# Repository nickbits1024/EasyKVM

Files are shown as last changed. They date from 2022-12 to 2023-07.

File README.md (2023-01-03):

# _Easy KVM_

## About Easy KVM

Easy KVM is a Wi-Fi enabled hybrid KVM.  It acts a an USB sharing switch and VESA DDC/CI switcher.  It does not touch the video signal which eliminates a lot of issues found with standard KVMs.

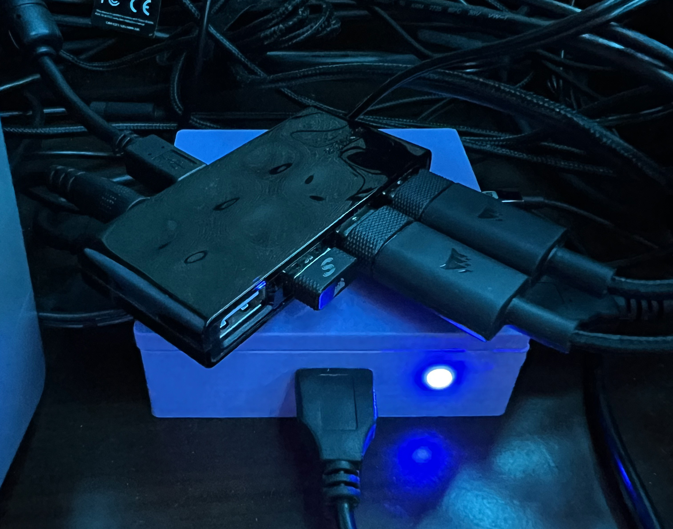
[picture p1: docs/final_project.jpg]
Final Project

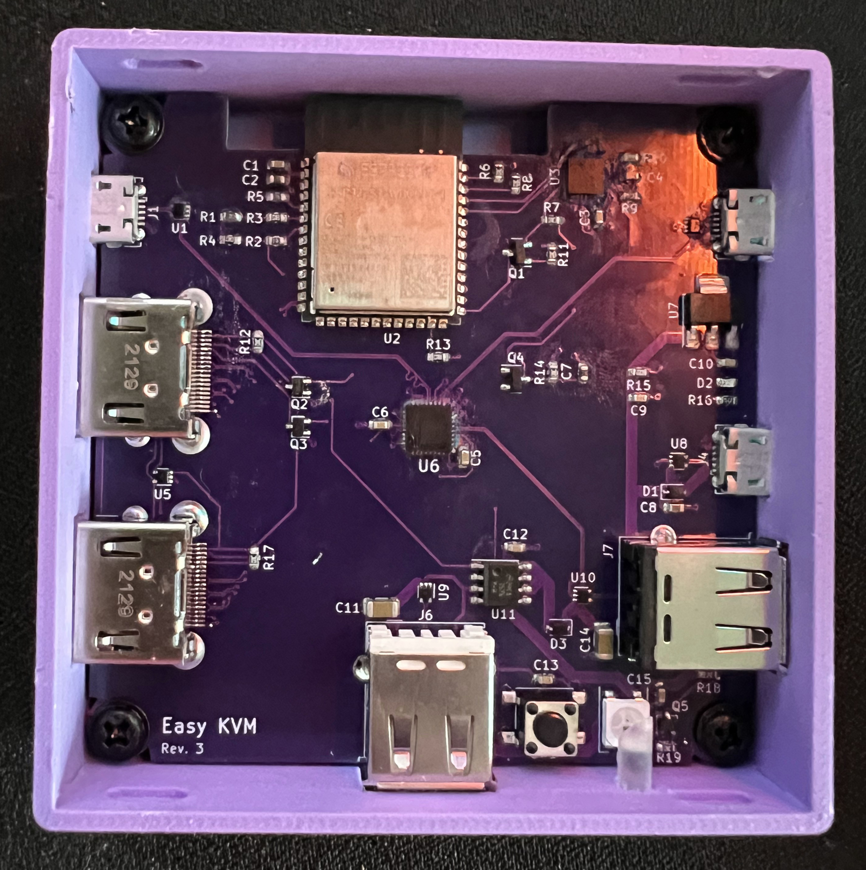
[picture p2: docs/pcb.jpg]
PCB

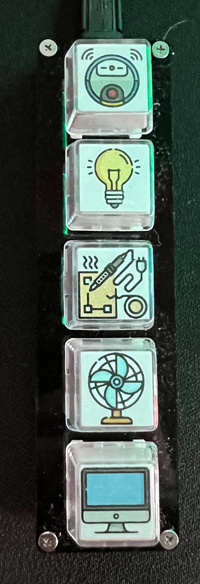
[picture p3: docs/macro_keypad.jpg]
Macro keypad


## Features

* Single USB 2.0 high speed capable port to be used with an external USB hub
* Wi-Fi control
* HDMI passthrough
* USB keyboard for macros and port switching
* Control monitor power state
* Integrated with Home Assistant

## External Requirements
* USB macro keypad e.g. [Amazon](https://www.amazon.com/gp/product/B09CKT8B7Y) [AliExpress](https://www.aliexpress.us/item/3256804248423460.html)
* USB 2.0 high speed hub e.g. [Amazon](https://www.amazon.com/gp/product/B005A0B3FG)
* Monitor with an HDMI port that supports VESA DDC/CI

## Port Setup
1. Connect source HDMI cable from video card to either one of the HDMI ports
2. Connect other HDMI port to monitor
3. Connect J1 Micro USB (top left) to PC1 USB
4. Connect J2 Micro USB (top right) to PC2 USB
5. Connect J6 Micro USB (bottom renter) to macro keypad
6. Connect J7 USB (bottom right) to USB hub
7. Connect J4 Micro USB (Center right) to either USB power or PC (for programming and serial monitoring)

## Wi-Fi Setup
Wi-Fi network selection is done through bluetooth.  
1. Download nRF Connect and connect to KVM
2. Open the client services tab and click Write Value the (up arrow) on the characteristic ending with an UUID of 29.  
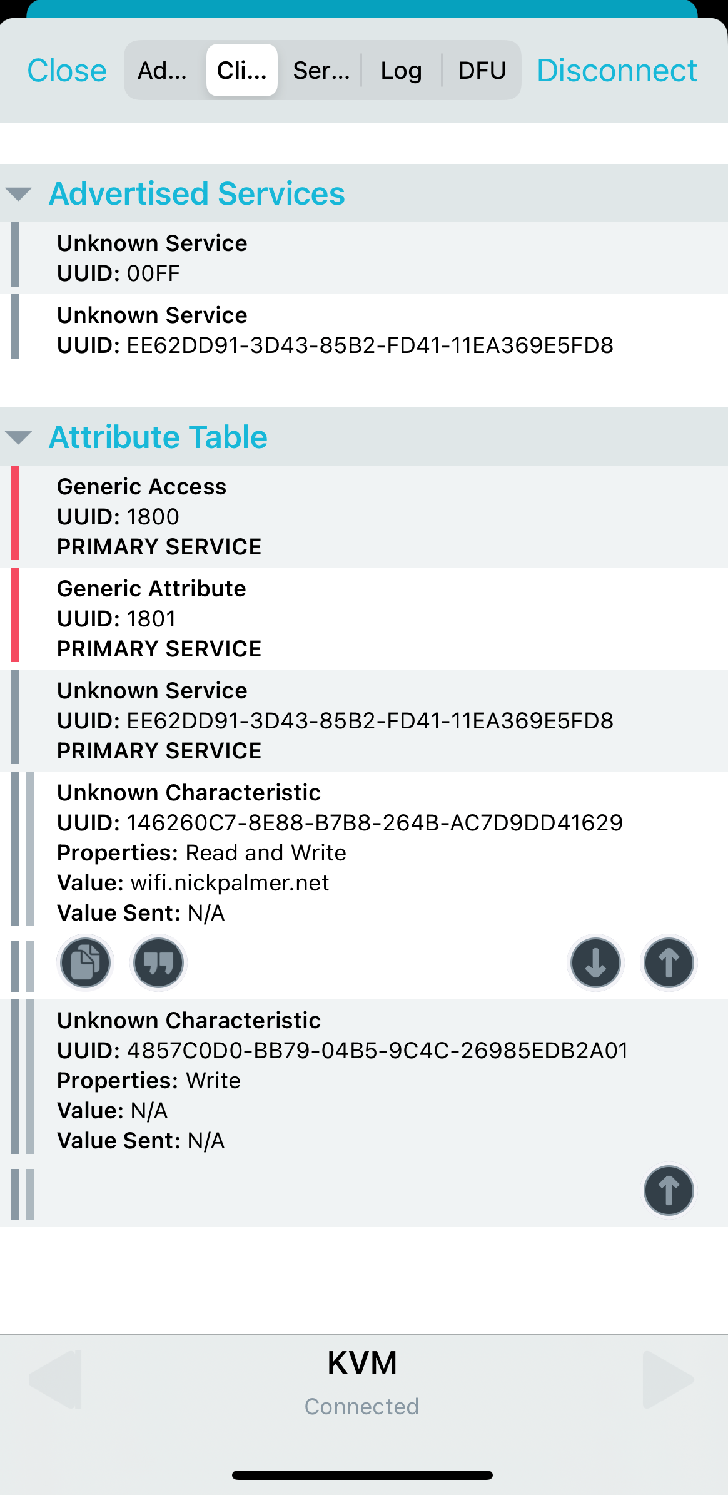
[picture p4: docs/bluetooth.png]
Characteristics

3. Click the UTF-8 tab and enter the network SSID and click Write.
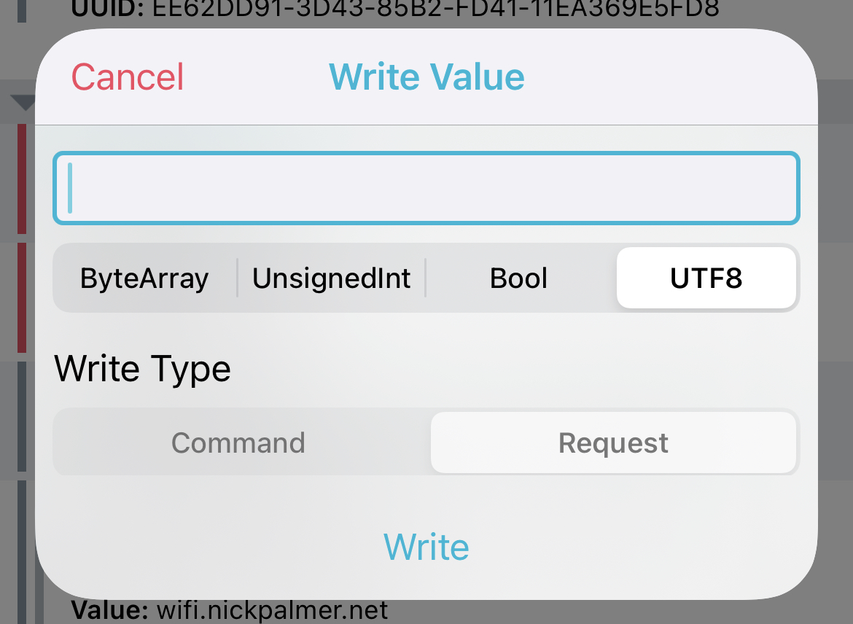
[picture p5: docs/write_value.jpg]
Write Value Screenshot

4. Click Write Value on the characteristic ending in 01.  This is the Wi-Fi password.  After clicking Write, the KVM should connect to the network.

## WebServer End Points

| URL | Method | Function | Payload |
| --- | --- | --- | --- |
|/config|GET|Open configuration page||
|/monitor|GET|Return monitor state|`{	"on":	true }`|
|/monitor|POST|Set monitor state|`{	"on":	true }`|
|/kvm|GET|Return selected KVM port|`{ "kvm":	1 }`|
|/kvm/1|GET|Select KVM port 1||
|/kvm/2|GET|Select KVM port 2||

## Home Assistant
The KVM needs a Long-Lived Access Token to interact with home assistant.  Create one from the home assistant profile page and save it for later (e.g. notepad)

### Monitor Switch

Copy code below into the home assistant switches.yaml file.  This will create a switch in home assistant that can be used to turn the connected monitor on and off.
```
- platform: rest
  name: "Office Monitor"
  unique_id: 08a5830e-3309-4998-9d17-7ea7ecf154fd
  resource: http://<<KVM_HOST_NAME_OR_IP>>/monitor
  timeout: 30
  body_on: '{"on": true}'
  body_off: '{"on": false}'
  is_on_template: "{{ value_json.on }}"
  headers:
    Content-Type: application/json
```

## Configuration
1. Determine the IP of the KVM either from router UI or connecting the KVM to a computer and viewing the serial output.
2. Navigate to http://KVM_IP/config
3. Select the desired source and RGB led color for each input
4. Enter home assistant URL and previously created access token
5. Configure the macro keypad functions
6. Click save

Note clipboard import/export only work if you have the KVM behind an https proxy

## Usage
Once properly configured, the inputs can be switched using the configured macro keypad button or through the web server end points

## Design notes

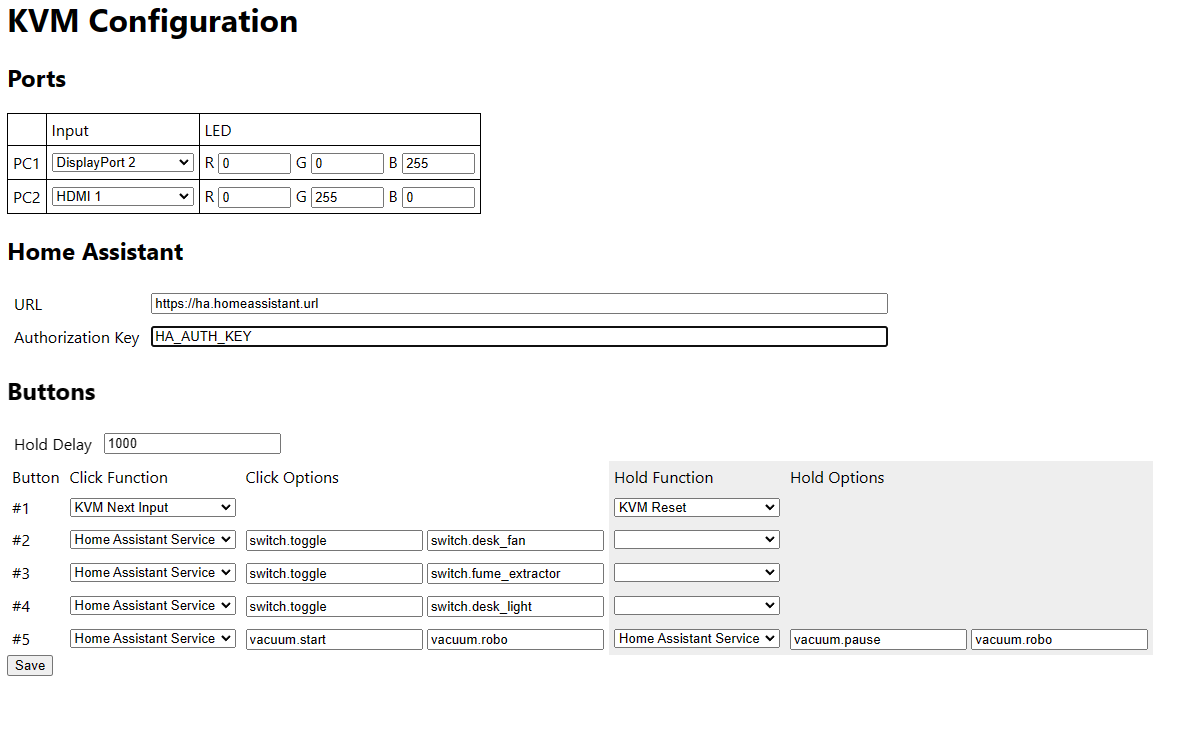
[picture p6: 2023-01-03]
docs/config.png

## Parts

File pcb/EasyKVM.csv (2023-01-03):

Source: | C:\Users\Nick\repos\EasyKVM\pcb\EasyKVM.kicad_sch
Date: | 12/30/2022 3:57:13 PM
Tool: | Eeschema (6.0.8)
Generator: | C:\Program Files\KiCad\6.0\bin\scripting\plugins/bom_csv_grouped_by_value.py
Component Count: | 62
Individual Components:
Item | Qty | Reference(s) | Value | LibPart | Footprint | Datasheet | Description | Height | Manufacturer_Name | Manufacturer_Part_Number | Mouser Part Number | Mouser Price/Stock
 |  | C1 | 0.1uF | Device:C | Capacitor_SMD:C_0603_1608Metric | ~
 |  | C2 | 10uF | Device:C | Capacitor_SMD:C_0603_1608Metric | ~
 |  | C3 | 4.7uF | Device:C | Capacitor_SMD:C_0603_1608Metric | ~
 |  | C4 | 0.1uF | Device:C | Capacitor_SMD:C_0603_1608Metric | ~
 |  | C5 | 0.1uF | Device:C | Capacitor_SMD:C_0603_1608Metric | ~
 |  | C6 | 0.1uF | Device:C | Capacitor_SMD:C_0603_1608Metric | ~
 |  | C7 | 1uF | Device:C | Capacitor_SMD:C_0603_1608Metric | ~
 |  | C8 | 10uF | Device:C | Capacitor_SMD:C_0603_1608Metric | ~
 |  | C9 | 4.7uF | Device:C | Capacitor_SMD:C_0603_1608Metric | ~
 |  | C10 | 4.7uF | Device:C | Capacitor_SMD:C_0603_1608Metric | ~
 |  | C11 | 100uF | Device:C | Capacitor_SMD:C_1206_3216Metric | ~
 |  | C12 | 0.1uF | Device:C | Capacitor_SMD:C_0603_1608Metric | ~
 |  | C13 | 0.1uF | Device:C | Capacitor_SMD:C_0603_1608Metric | ~
 |  | C14 | 100uF | Device:C | Capacitor_SMD:C_1206_3216Metric | ~
 |  | C15 | 0.1uF | Device:C | Capacitor_SMD:C_0603_1608Metric | ~
 |  | D1 | 1N5819 | Diode:1N5819 | Diode_SMD:D_SOD-323 | http://www.vishay.com/docs/88525/1n5817.pdf
 |  | D2 | RED LED | Device:LED | Capacitor_SMD:C_0603_1608Metric | ~
 |  | D3 | 1N5819 | Diode:1N5819 | Diode_SMD:D_SOD-323 | http://www.vishay.com/docs/88525/1n5817.pdf
 |  | D4 | SK6812 | LED:SK6812 | LED_SMD:LED_SK6812_PLCC4_5.0x5.0mm_P3.2mm | https://cdn-shop.adafruit.com/product-files/1138/SK6812+LED+datasheet+.pdf
 |  | J1 | USB_B_Micro | Connector:USB_B_Micro | Connector_USB:USB_Micro-B_Molex-105017-0001 | ~
 |  | J2 | USB_B_Micro | Connector:USB_B_Micro | Connector_USB:USB_Micro-B_Molex-105017-0001 | ~
 |  | J3 | HDMI_A | Connector:HDMI_A | MyParts:2086581051 | https://en.wikipedia.org/wiki/HDMI
 |  | J4 | USB_B_Micro | Connector:USB_B_Micro | Connector_USB:USB_Micro-B_Molex-105017-0001 | ~
 |  | J5 | HDMI_A | Connector:HDMI_A | MyParts:2086581051 | https://en.wikipedia.org/wiki/HDMI
 |  | J6 | USB_A | Connector:USB_A | Connector_USB:USB_A_Molex_67643_Horizontal | ~
 |  | J7 | USB_A | Connector:USB_A | Connector_USB:USB_A_Molex_67643_Horizontal | ~
 |  | Q1 | MMBT3904 | Transistor_BJT:MMBT3904 | Package_TO_SOT_SMD:SOT-23 | https://www.onsemi.com/pub/Collateral/2N3903-D.PDF
 |  | Q2 | BSS138 | Transistor_FET:BSS138 | Package_TO_SOT_SMD:SOT-323_SC-70 | https://www.onsemi.com/pub/Collateral/BSS138-D.PDF
 |  | Q3 | BSS138 | Transistor_FET:BSS138 | Package_TO_SOT_SMD:SOT-323_SC-70 | https://www.onsemi.com/pub/Collateral/BSS138-D.PDF
 |  | Q4 | MMBT3904 | Transistor_BJT:MMBT3904 | Package_TO_SOT_SMD:SOT-23 | https://www.onsemi.com/pub/Collateral/2N3903-D.PDF
 |  | Q5 | BSS138 | Transistor_FET:BSS138 | Package_TO_SOT_SMD:SOT-323_SC-70 | https://www.onsemi.com/pub/Collateral/BSS138-D.PDF
 |  | R1 | 100K | Device:R | Resistor_SMD:R_0603_1608Metric | ~
 |  | R2 | 1K | Device:R | Resistor_SMD:R_0603_1608Metric | ~
 |  | R3 | 1K | Device:R | Resistor_SMD:R_0603_1608Metric | ~
 |  | R4 | 100K | Device:R | Resistor_SMD:R_0603_1608Metric | ~
 |  | R5 | 1K | Device:R | Resistor_SMD:R_0603_1608Metric | ~
 |  | R6 | 10K | Device:R | Resistor_SMD:R_0603_1608Metric | ~
 |  | R7 | 10K | Device:R | Resistor_SMD:R_0603_1608Metric | ~
 |  | R8 | 10K | Device:R | Resistor_SMD:R_0603_1608Metric | ~
 |  | R9 | 47K | Device:R | Resistor_SMD:R_0603_1608Metric | ~
 |  | R10 | 1K | Device:R | Resistor_SMD:R_0603_1608Metric | ~
 |  | R11 | 10K | Device:R | Resistor_SMD:R_0603_1608Metric | ~
 |  | R12 | 10K | Device:R | Resistor_SMD:R_0603_1608Metric | ~
 |  | R13 | 1K | Device:R | Resistor_SMD:R_0603_1608Metric | ~
 |  | R14 | 10K | Device:R | Resistor_SMD:R_0603_1608Metric | ~
 |  | R15 | 22K | Device:R | Resistor_SMD:R_0603_1608Metric | ~
 |  | R16 | 5.1K | Device:R | Resistor_SMD:R_0603_1608Metric | ~
 |  | R17 | 10K | Device:R | Resistor_SMD:R_0603_1608Metric | ~
 |  | R18 | 10K | Device:R | Resistor_SMD:R_0603_1608Metric | ~
 |  | R19 | 10K | Device:R | Resistor_SMD:R_0603_1608Metric | ~
 |  | SW1 | RESET | Switch:SW_Push | Button_Switch_SMD:SW_Push_1P1T_NO_6x6mm_H9.5mm | ~
 |  | U1 | SP3003-02XTG | :SP3003-02XTG_3 | Package_TO_SOT_SMD:Diodes_SOT-553
 |  | U2 | ESP32-S3-WROOM-1 | Espressif:ESP32-S3-WROOM-1 | Espressif:ESP32-S3-WROOM-1 | https://www.espressif.com/sites/default/files/documentation/esp32-s3-wroom-1_wroom-1u_datasheet_en.pdf
 |  | U3 | CP2102N-Axx-xQFN24 | Interface_USB:CP2102N-Axx-xQFN24 | Package_DFN_QFN:QFN-24-1EP_4x4mm_P0.5mm_EP2.6x2.6mm | https://www.silabs.com/documents/public/data-sheets/cp2102n-datasheet.pdf
 |  | U4 | SP3003-02XTG | :SP3003-02XTG_4 | Package_TO_SOT_SMD:Diodes_SOT-553
 |  | U5 | SP3003-02XTG | MyParts:SP3003-02XTG | Package_TO_SOT_SMD:Diodes_SOT-553
 |  | U6 | MAX4999ETJ+ | MAX4999ETJ+:MAX4999ETJ+ | MyParts:QFN50P500X500X80-33N | https://datasheets.maximintegrated.com/en/ds/MAX4999.pdf | Maxim MAX4999ETJ+, Multiplexer Single 8:1 Multiplexer, 3 3.6 V, 32-Pin TQFN | 0.8 | Maxim Integrated | MAX4999ETJ+ | 700-MAX4999ETJ | https://www.mouser.co.uk/ProductDetail/Maxim-Integrated/MAX4999ETJ%2b?qs=LHmEVA8xxfbu5fCaz0LQrg%3D%3D
 |  | U7 | AP7361C-33E | Regulator_Linear:AP7361C-33E | Package_TO_SOT_SMD:SOT-223-3_TabPin2 | https://www.diodes.com/assets/Datasheets/AP7361C.pdf
 |  | U8 | SP3003-02XTG | :SP3003-02XTG_2 | Package_TO_SOT_SMD:Diodes_SOT-553
 |  | U9 | SP3003-02XTG | :SP3003-02XTG_5 | Package_TO_SOT_SMD:Diodes_SOT-553
 |  | U10 | SP3003-02XTG | :SP3003-02XTG_1 | Package_TO_SOT_SMD:Diodes_SOT-553
 |  | U11 | LM3525M-H | MyParts:LM3525M-H | Package_SO:SOIC-8_3.9x4.9mm_P1.27mm
Collated Components:
Item | Qty | Reference(s) | Value | LibPart | Footprint | Datasheet | Description | Height | Manufacturer_Name | Manufacturer_Part_Number | Mouser Part Number | Mouser Price/Stock
1 | 7 | C1, C4, C5, C6, C12, C13, C15 | 0.1uF | Device:C | Capacitor_SMD:C_0603_1608Metric | ~
2 | 2 | C2, C8 | 10uF | Device:C | Capacitor_SMD:C_0603_1608Metric | ~
3 | 3 | C3, C9, C10 | 4.7uF | Device:C | Capacitor_SMD:C_0603_1608Metric | ~
4 | 1 | C7 | 1uF | Device:C | Capacitor_SMD:C_0603_1608Metric | ~
5 | 2 | C11, C14 | 100uF | Device:C | Capacitor_SMD:C_1206_3216Metric | ~
6 | 2 | D1, D3 | 1N5819 | Diode:1N5819 | Diode_SMD:D_SOD-323 | http://www.vishay.com/docs/88525/1n5817.pdf
7 | 1 | D2 | RED LED | Device:LED | Capacitor_SMD:C_0603_1608Metric | ~
8 | 1 | D4 | SK6812 | LED:SK6812 | LED_SMD:LED_SK6812_PLCC4_5.0x5.0mm_P3.2mm | https://cdn-shop.adafruit.com/product-files/1138/SK6812+LED+datasheet+.pdf
9 | 3 | J1, J2, J4 | USB_B_Micro | Connector:USB_B_Micro | Connector_USB:USB_Micro-B_Molex-105017-0001 | ~
10 | 2 | J3, J5 | HDMI_A | Connector:HDMI_A | MyParts:2086581051 | https://en.wikipedia.org/wiki/HDMI
11 | 2 | J6, J7 | USB_A | Connector:USB_A | Connector_USB:USB_A_Molex_67643_Horizontal | ~
12 | 2 | Q1, Q4 | MMBT3904 | Transistor_BJT:MMBT3904 | Package_TO_SOT_SMD:SOT-23 | https://www.onsemi.com/pub/Collateral/2N3903-D.PDF
13 | 3 | Q2, Q3, Q5 | BSS138 | Transistor_FET:BSS138 | Package_TO_SOT_SMD:SOT-323_SC-70 | https://www.onsemi.com/pub/Collateral/BSS138-D.PDF
14 | 2 | R1, R4 | 100K | Device:R | Resistor_SMD:R_0603_1608Metric | ~
15 | 5 | R2, R3, R5, R10, R13 | 1K | Device:R | Resistor_SMD:R_0603_1608Metric | ~
16 | 9 | R6, R7, R8, R11, R12, R14, R17, R18, R19 | 10K | Device:R | Resistor_SMD:R_0603_1608Metric | ~
17 | 1 | R9 | 47K | Device:R | Resistor_SMD:R_0603_1608Metric | ~
18 | 1 | R15 | 22K | Device:R | Resistor_SMD:R_0603_1608Metric | ~
19 | 1 | R16 | 5.1K | Device:R | Resistor_SMD:R_0603_1608Metric | ~
20 | 1 | SW1 | RESET | Switch:SW_Push | Button_Switch_SMD:SW_Push_1P1T_NO_6x6mm_H9.5mm | ~
21 | 1 | U1 | SP3003-02XTG | :SP3003-02XTG_3 | Package_TO_SOT_SMD:Diodes_SOT-553
22 | 1 | U2 | ESP32-S3-WROOM-1 | Espressif:ESP32-S3-WROOM-1 | Espressif:ESP32-S3-WROOM-1 | https://www.espressif.com/sites/default/files/documentation/esp32-s3-wroom-1_wroom-1u_datasheet_en.pdf
23 | 1 | U3 | CP2102N-Axx-xQFN24 | Interface_USB:CP2102N-Axx-xQFN24 | Package_DFN_QFN:QFN-24-1EP_4x4mm_P0.5mm_EP2.6x2.6mm | https://www.silabs.com/documents/public/data-sheets/cp2102n-datasheet.pdf
24 | 1 | U4 | SP3003-02XTG | :SP3003-02XTG_4 | Package_TO_SOT_SMD:Diodes_SOT-553
25 | 1 | U5 | SP3003-02XTG | MyParts:SP3003-02XTG | Package_TO_SOT_SMD:Diodes_SOT-553
26 | 1 | U6 | MAX4999ETJ+ | MAX4999ETJ+:MAX4999ETJ+ | MyParts:QFN50P500X500X80-33N | https://datasheets.maximintegrated.com/en/ds/MAX4999.pdf | Maxim MAX4999ETJ+, Multiplexer Single 8:1 Multiplexer, 3 3.6 V, 32-Pin TQFN | 0.8 | Maxim Integrated | MAX4999ETJ+ | 700-MAX4999ETJ | https://www.mouser.co.uk/ProductDetail/Maxim-Integrated/MAX4999ETJ%2b?qs=LHmEVA8xxfbu5fCaz0LQrg%3D%3D
27 | 1 | U7 | AP7361C-33E | Regulator_Linear:AP7361C-33E | Package_TO_SOT_SMD:SOT-223-3_TabPin2 | https://www.diodes.com/assets/Datasheets/AP7361C.pdf
28 | 1 | U8 | SP3003-02XTG | :SP3003-02XTG_2 | Package_TO_SOT_SMD:Diodes_SOT-553
29 | 1 | U9 | SP3003-02XTG | :SP3003-02XTG_5 | Package_TO_SOT_SMD:Diodes_SOT-553
30 | 1 | U10 | SP3003-02XTG | :SP3003-02XTG_1 | Package_TO_SOT_SMD:Diodes_SOT-553
31 | 1 | U11 | LM3525M-H | MyParts:LM3525M-H | Package_SO:SOIC-8_3.9x4.9mm_P1.27mm

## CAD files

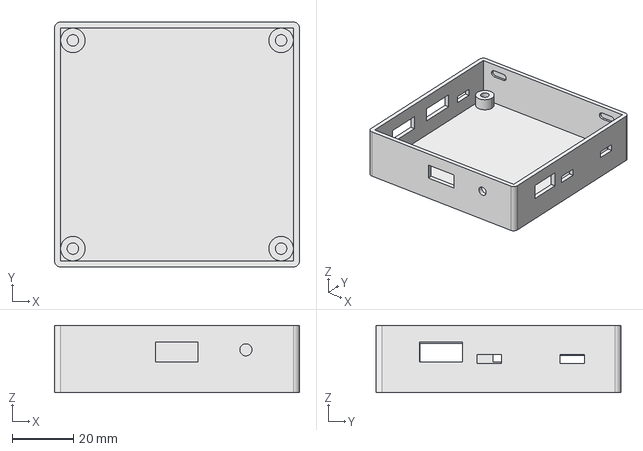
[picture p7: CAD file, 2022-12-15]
cad/Bottom.step
80.0 x 80.0 x 22.0 mm

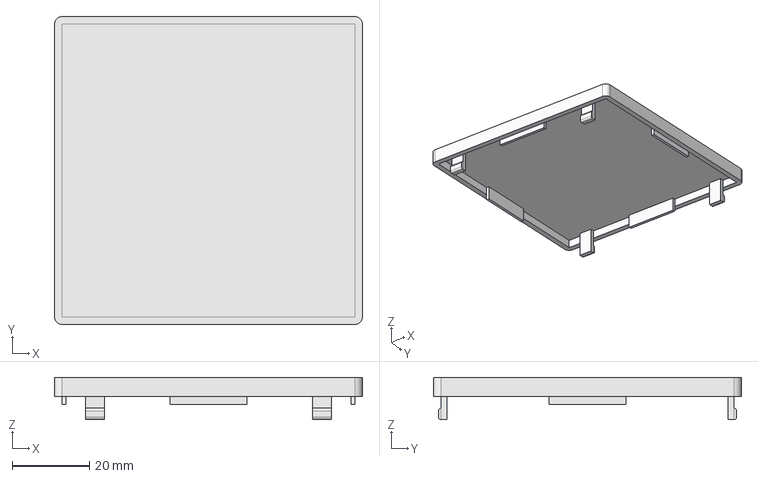
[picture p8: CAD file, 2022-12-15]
cad/Top.step
80.0 x 80.0 x 11.0 mm

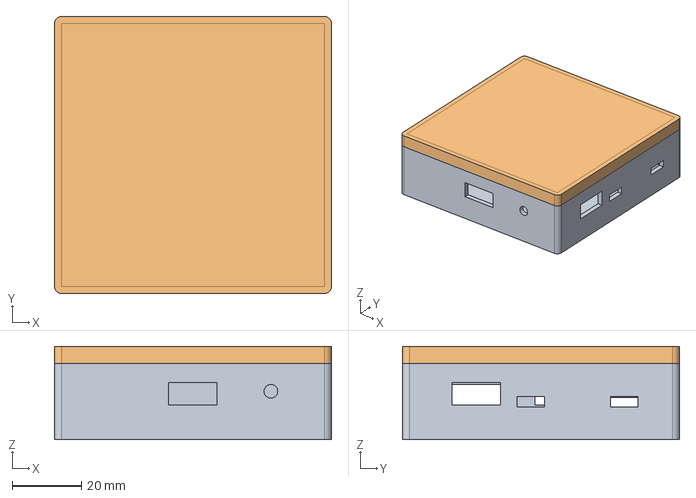
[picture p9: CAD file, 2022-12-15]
cad/EasyKVM-case.FCStd
80.0 x 80.0 x 27.0 mm
Bottom
Top

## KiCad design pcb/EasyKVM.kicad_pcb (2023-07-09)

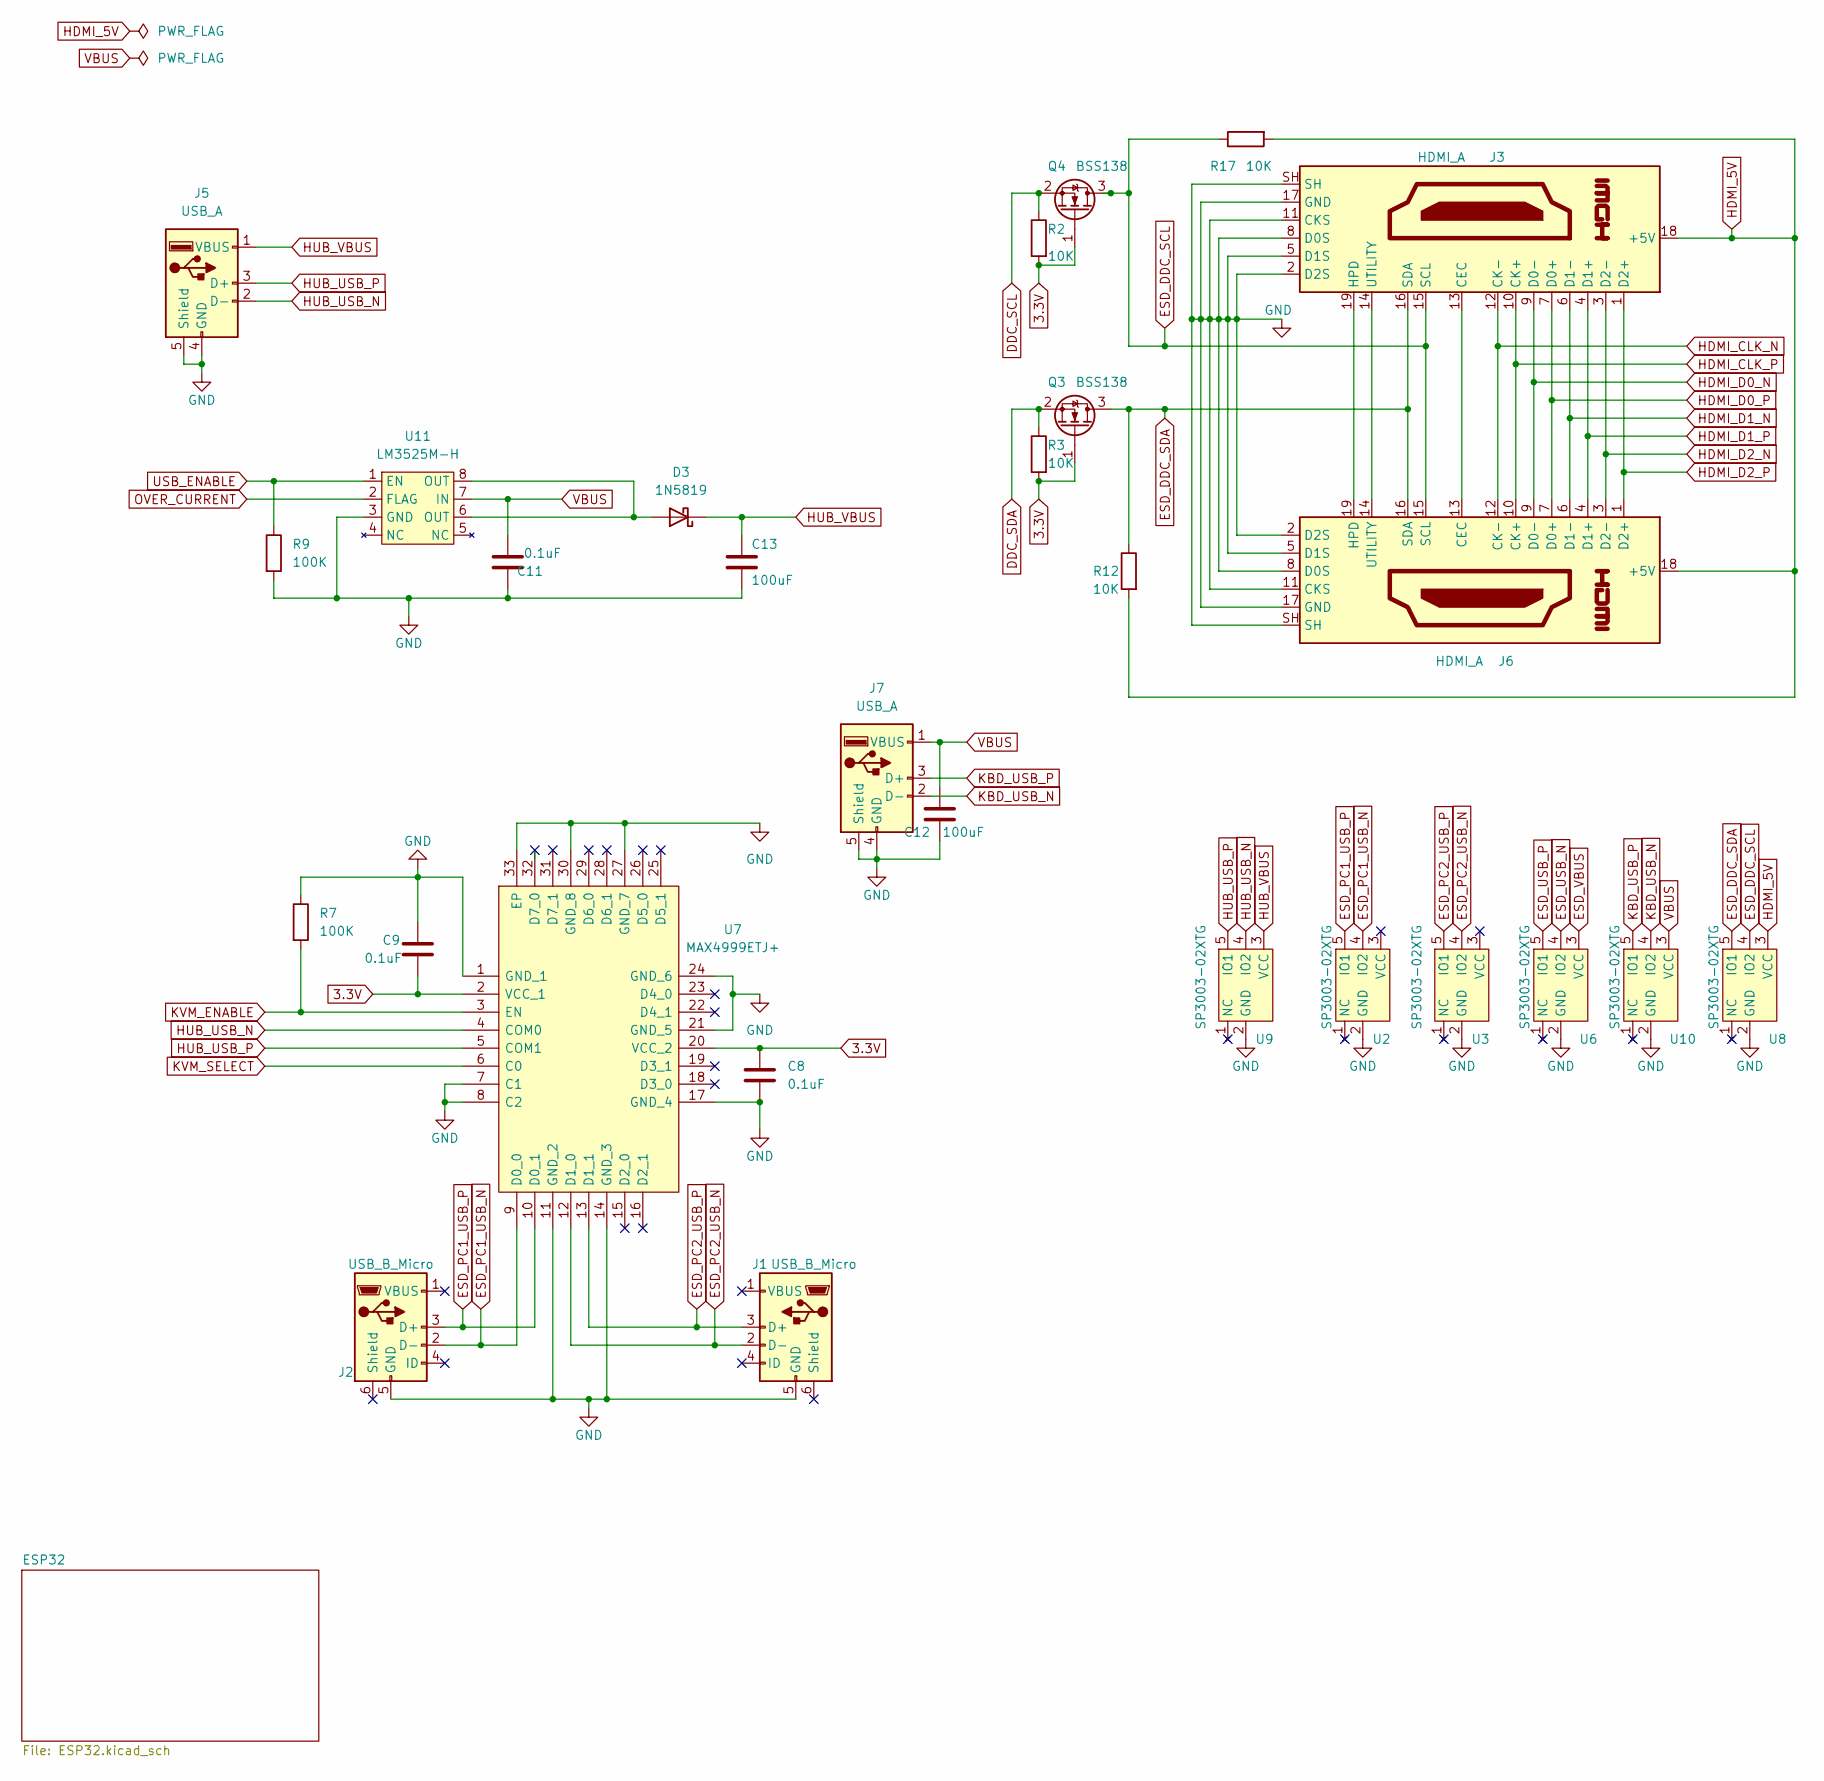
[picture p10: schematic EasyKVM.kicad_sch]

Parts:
C8, C9, C11: 0.1uF; C_0603_1608Metric
C12, C13: 100uF; C_1206_3216Metric
D3: 1N5819; D_SOD-323
J1, J2: USB_B_Micro; USB_Micro-B_Molex-105017-0001
J3, J6: HDMI_A; 2086581051
J5, J7: USB_A; USB_A_Molex_67643_Horizontal
Q3, Q4: BSS138; SOT-323_SC-70
R2, R3, R12, R17: 10K; R_0603_1608Metric
R7, R9: 100K; R_0603_1608Metric
U2, U3, U6, U8, U9, U10: SP3003-02XTG; Diodes_SOT-553
U7: MAX4999ETJ+; QFN50P500X500X80-33N; Manufacturer_Part_Number MAX4999ETJ+; Mouser Part Number 700-MAX4999ETJ
U11: LM3525M-H; SOIC-8_3.9x4.9mm_P1.27mm

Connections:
3.3V: C8.2, C9.1, Q3.1 (G), Q4.1 (G), R2.2, R3.2, U7.2 (VCC_1), U7.20 (VCC_2); also elsewhere on the board
DDC_SCL: Q4.2 (S), R2.1; also elsewhere on the board
DDC_SDA: Q3.2 (S), R3.1; also elsewhere on the board
ESD_DDC_SCL: J3.15 (SCL), J6.15 (SCL), Q4.3 (D), R17.1, U8.4 (IO2)
ESD_DDC_SDA: J3.16 (SDA), J6.16 (SDA), Q3.3 (D), R12.1, U8.5 (IO1)
ESD_PC1_USB_N: J2.2 (D-), U2.4 (IO2), U7.9 (D0_0)
ESD_PC1_USB_P: J2.3 (D+), U2.5 (IO1), U7.10 (D0_1)
ESD_PC2_USB_N: J1.2 (D-), U3.4 (IO2), U7.12 (D1_0)
ESD_PC2_USB_P: J1.3 (D+), U3.5 (IO1), U7.13 (D1_1)
ESD_USB_N: U6.4 (IO2); also elsewhere on the board
ESD_USB_P: U6.5 (IO1); also elsewhere on the board
ESD_VBUS: U6.3 (VCC); also elsewhere on the board
GND: C8.1, C9.2, C11.2, C12.2, C13.1, J1.5 (GND), J2.5 (GND), J3.2 (D2S), J3.5 (D1S), J3.8 (D0S), J3.11 (CKS), J3.17 (GND), J3.SH, J5.4 (GND), J5.5 (Shield), J6.2 (D2S), J6.5 (D1S), J6.8 (D0S), J6.11 (CKS), J6.17 (GND), J6.SH, J7.4 (GND), J7.5 (Shield), R7.1, R9.2, U2.2 (GND), U3.2 (GND), U6.2 (GND), U7.1 (GND_1), U7.7 (C1), U7.8 (C2), U7.11 (GND_2), U7.14 (GND_3), U7.17 (GND_4), U7.21 (GND_5), U7.24 (GND_6), U7.27 (GND_7), U7.30 (GND_8), U7.33 (EP), U8.2 (GND), U9.2 (GND), U10.2 (GND), U11.3 (GND); also elsewhere on the board
HDMI_5V: J3.18 (+5V), J6.18 (+5V), R12.2, R17.2, U8.3 (VCC)
HDMI_CLK_N: J3.12 (CK-), J6.12 (CK-)
HDMI_CLK_P: J3.10 (CK+), J6.10 (CK+)
HDMI_D0_N: J3.9 (D0-), J6.9 (D0-)
HDMI_D0_P: J3.7 (D0+), J6.7 (D0+)
HDMI_D1_N: J3.6 (D1-), J6.6 (D1-)
HDMI_D1_P: J3.4 (D1+), J6.4 (D1+)
HDMI_D2_N: J3.3 (D2-), J6.3 (D2-)
HDMI_D2_P: J3.1 (D2+), J6.1 (D2+)
HUB_USB_N: J5.2 (D-), U7.4 (COM0), U9.4 (IO2)
HUB_USB_P: J5.3 (D+), U7.5 (COM1), U9.5 (IO1)
HUB_VBUS: C13.2, D3.1 (K), J5.1 (VBUS), U9.3 (VCC)
KBD_USB_N: J7.2 (D-), U10.4 (IO2); also elsewhere on the board
KBD_USB_P: J7.3 (D+), U10.5 (IO1); also elsewhere on the board
KVM_ENABLE: R7.2, U7.3 (EN); also elsewhere on the board
KVM_SELECT: U7.6 (C0); also elsewhere on the board
unnamed: D3.2 (A), U11.6 (OUT), U11.8 (OUT)
unnamed: J3.13 (CEC), J6.13 (CEC)
unnamed: J3.14 (UTILITY), J6.14 (UTILITY)
unnamed: J3.19 (HPD), J6.19 (HPD)
OVER_CURRENT: U11.2 (FLAG); also elsewhere on the board
USB_ENABLE: R9.1, U11.1 (EN); also elsewhere on the board
VBUS: C11.1, C12.1, J7.1 (VBUS), U10.3 (VCC), U11.7 (IN); also elsewhere on the board

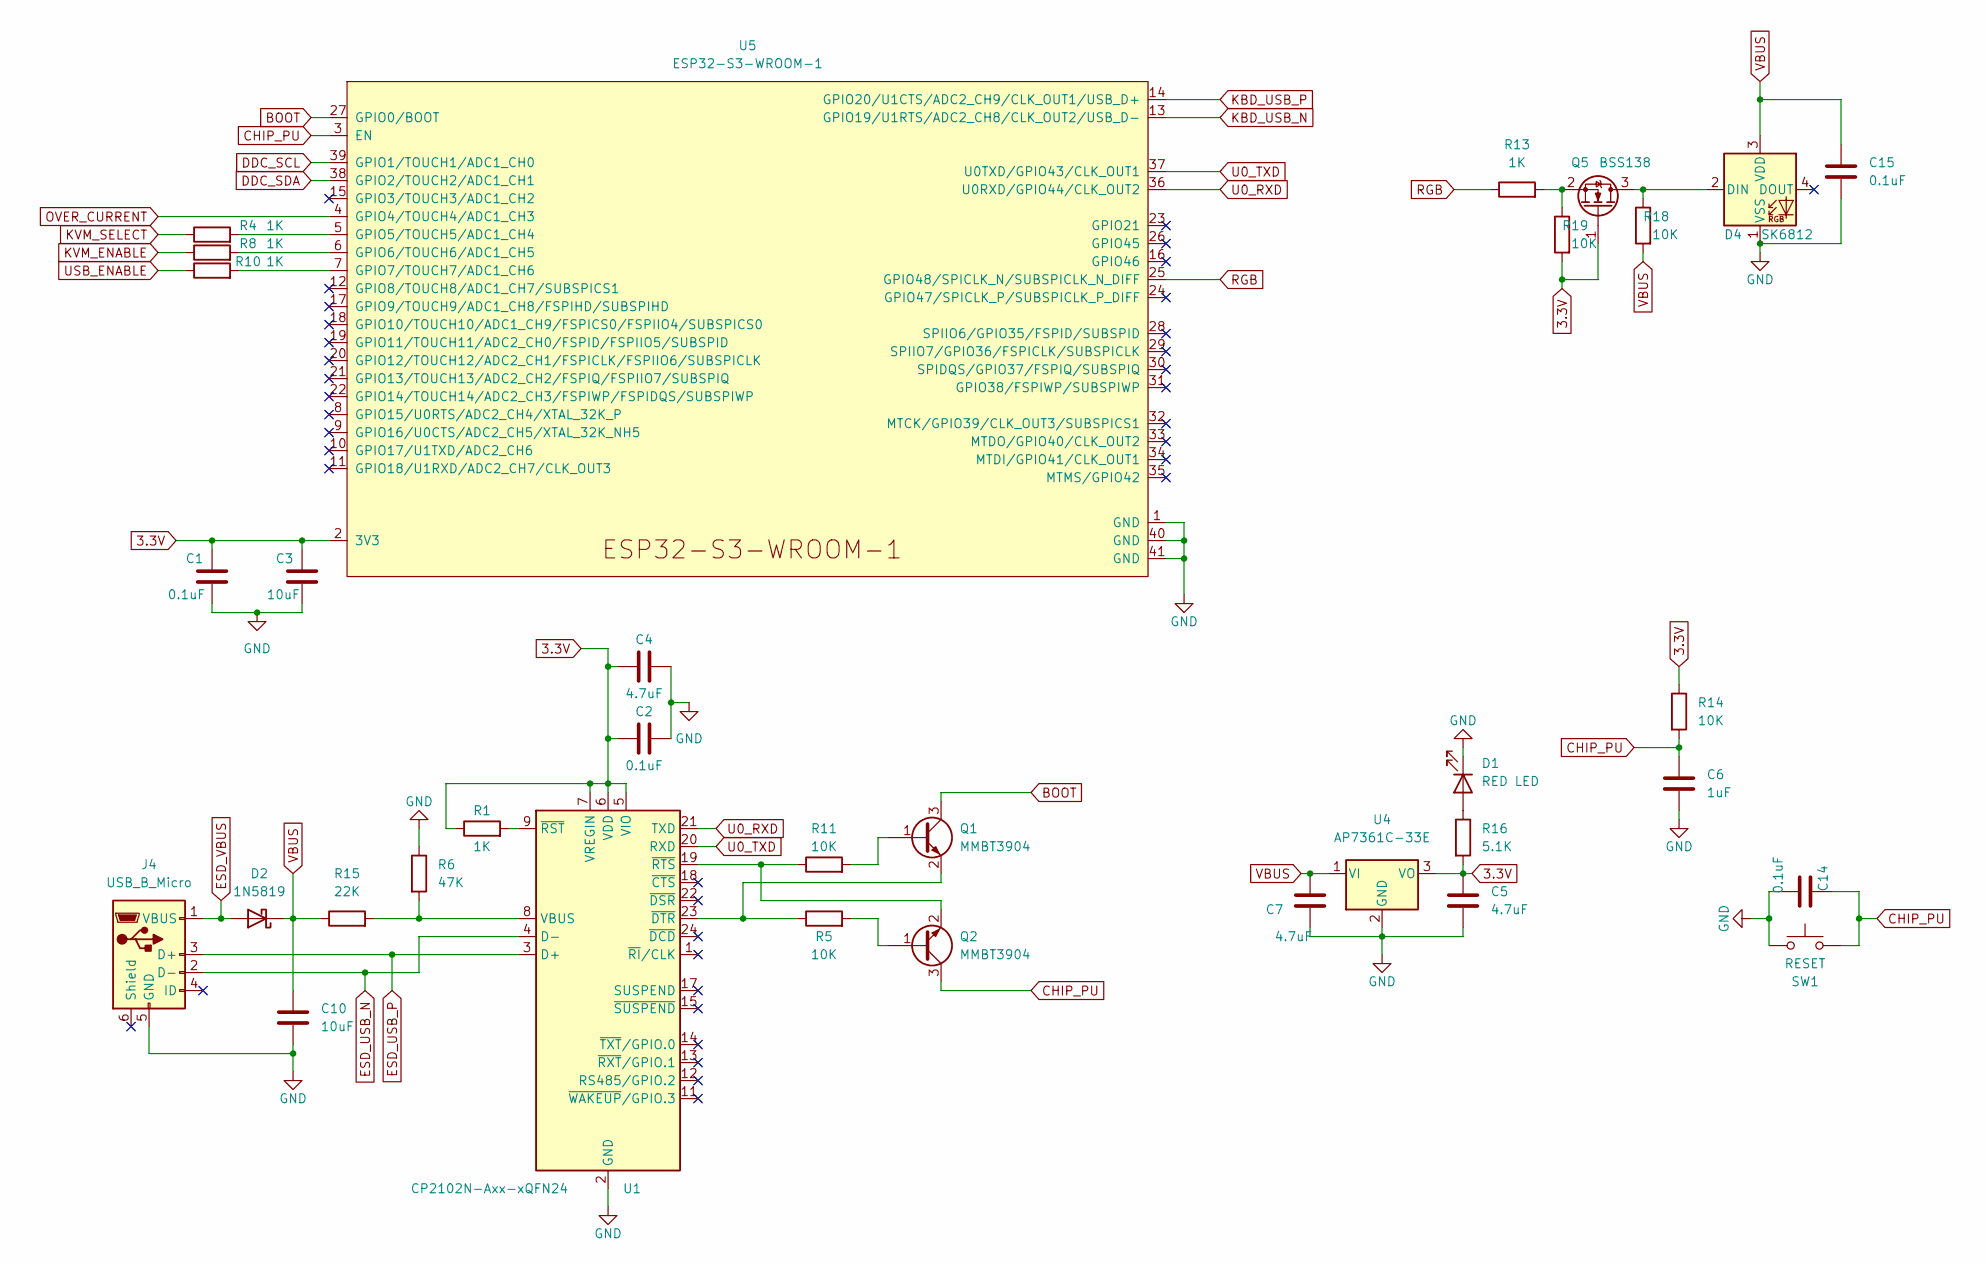
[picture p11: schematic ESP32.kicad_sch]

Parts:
C1, C2, C14, C15: 0.1uF; C_0603_1608Metric
C3, C10: 10uF; C_0603_1608Metric
C4, C5, C7: 4.7uF; C_0603_1608Metric
C6: 1uF; C_0603_1608Metric
D1: RED LED; LED_0603_1608Metric
D2: 1N5819; D_SOD-323
D4: SK6812; LED_SK6812_PLCC4_5.0x5.0mm_P3.2mm
J4: USB_B_Micro; USB_Micro-B_Molex-105017-0001
Q1, Q2: MMBT3904; SOT-23
Q5: BSS138; SOT-323_SC-70
R1, R4, R8, R10, R13: 1K; R_0603_1608Metric
R5, R11, R14, R18, R19: 10K; R_0603_1608Metric
R6: 47K; R_0603_1608Metric
R15: 22K; R_0603_1608Metric
R16: 5.1K; R_0603_1608Metric
SW1: RESET; SW_Push_1P1T_NO_6x6mm_H9.5mm
U1: CP2102N-Axx-xQFN24; QFN-24-1EP_4x4mm_P0.5mm_EP2.6x2.6mm
U4: AP7361C-33E; SOT-223-3_TabPin2
U5: ESP32-S3-WROOM-1

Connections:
3.3V: C1.1, C2.1, C3.1, C4.1, C5.2, Q5.1 (G), R1.1, R14.1, R16.2, R19.2, U1.5 (VIO), U1.6 (VDD), U1.7 (VREGIN), U4.3 (VO), U5.2 (3V3); also elsewhere on the board
BOOT: Q1.3 (C), U5.27 (GPIO0/BOOT)
CHIP_PU: C6.1, C14.1, Q2.3 (C), R14.2, SW1.2, U5.3 (EN)
DDC_SCL: U5.39 (GPIO1/TOUCH1/ADC1_CH0); also elsewhere on the board
DDC_SDA: U5.38 (GPIO2/TOUCH2/ADC1_CH1); also elsewhere on the board
ESD_USB_N: J4.2 (D-), U1.4 (D-); also elsewhere on the board
ESD_USB_P: J4.3 (D+), U1.3 (D+); also elsewhere on the board
ESD_VBUS: D2.2 (A), J4.1 (VBUS); also elsewhere on the board
GND: C1.2, C2.2, C3.2, C4.2, C5.1, C6.2, C7.1, C10.2, C14.2, C15.1, D1.1 (K), D4.1 (VSS), J4.5 (GND), R6.1, SW1.1, U1.2 (GND), U1.25 (GND), U4.2 (GND), U5.1 (GND), U5.40 (GND), U5.41 (GND); also elsewhere on the board
KBD_USB_N: U5.13 (GPIO19/U1RTS/ADC2_CH8/CLK_OUT2/USB_D-); also elsewhere on the board
KBD_USB_P: U5.14 (GPIO20/U1CTS/ADC2_CH9/CLK_OUT1/USB_D+); also elsewhere on the board
KVM_ENABLE: R8.1; also elsewhere on the board
KVM_SELECT: R4.1; also elsewhere on the board
unnamed: D1.2 (A), R16.1
unnamed: D4.2 (DIN), Q5.3 (D), R18.1
unnamed: Q1.1 (B), R11.2
unnamed: Q1.2 (E), R5.1, U1.23 (~DTR)
unnamed: Q2.1 (B), R5.2
unnamed: Q2.2 (E), R11.1, U1.19 (~RTS)
unnamed: Q5.2 (S), R13.2, R19.1
unnamed: R10.2, U5.7 (GPIO7/TOUCH7/ADC1_CH6)
unnamed: R8.2, U5.6 (GPIO6/TOUCH6/ADC1_CH5)
unnamed: R4.2, U5.5 (GPIO5/TOUCH5/ADC1_CH4)
unnamed: R1.2, U1.9 (~RST)
unnamed: R6.2, R15.2, U1.8 (VBUS)
OVER_CURRENT: U5.4 (GPIO4/TOUCH4/ADC1_CH3); also elsewhere on the board
RGB: R13.1, U5.25 (GPIO48/SPICLK_N/SUBSPICLK_N_DIFF)
U0_RXD: U1.21 (TXD), U5.36 (U0RXD/GPIO44/CLK_OUT2)
U0_TXD: U1.20 (RXD), U5.37 (U0TXD/GPIO43/CLK_OUT1)
USB_ENABLE: R10.1; also elsewhere on the board
VBUS: C7.2, C10.1, C15.2, D2.1 (K), D4.3 (VDD), R15.1, R18.2, U4.1 (VI); also elsewhere on the board

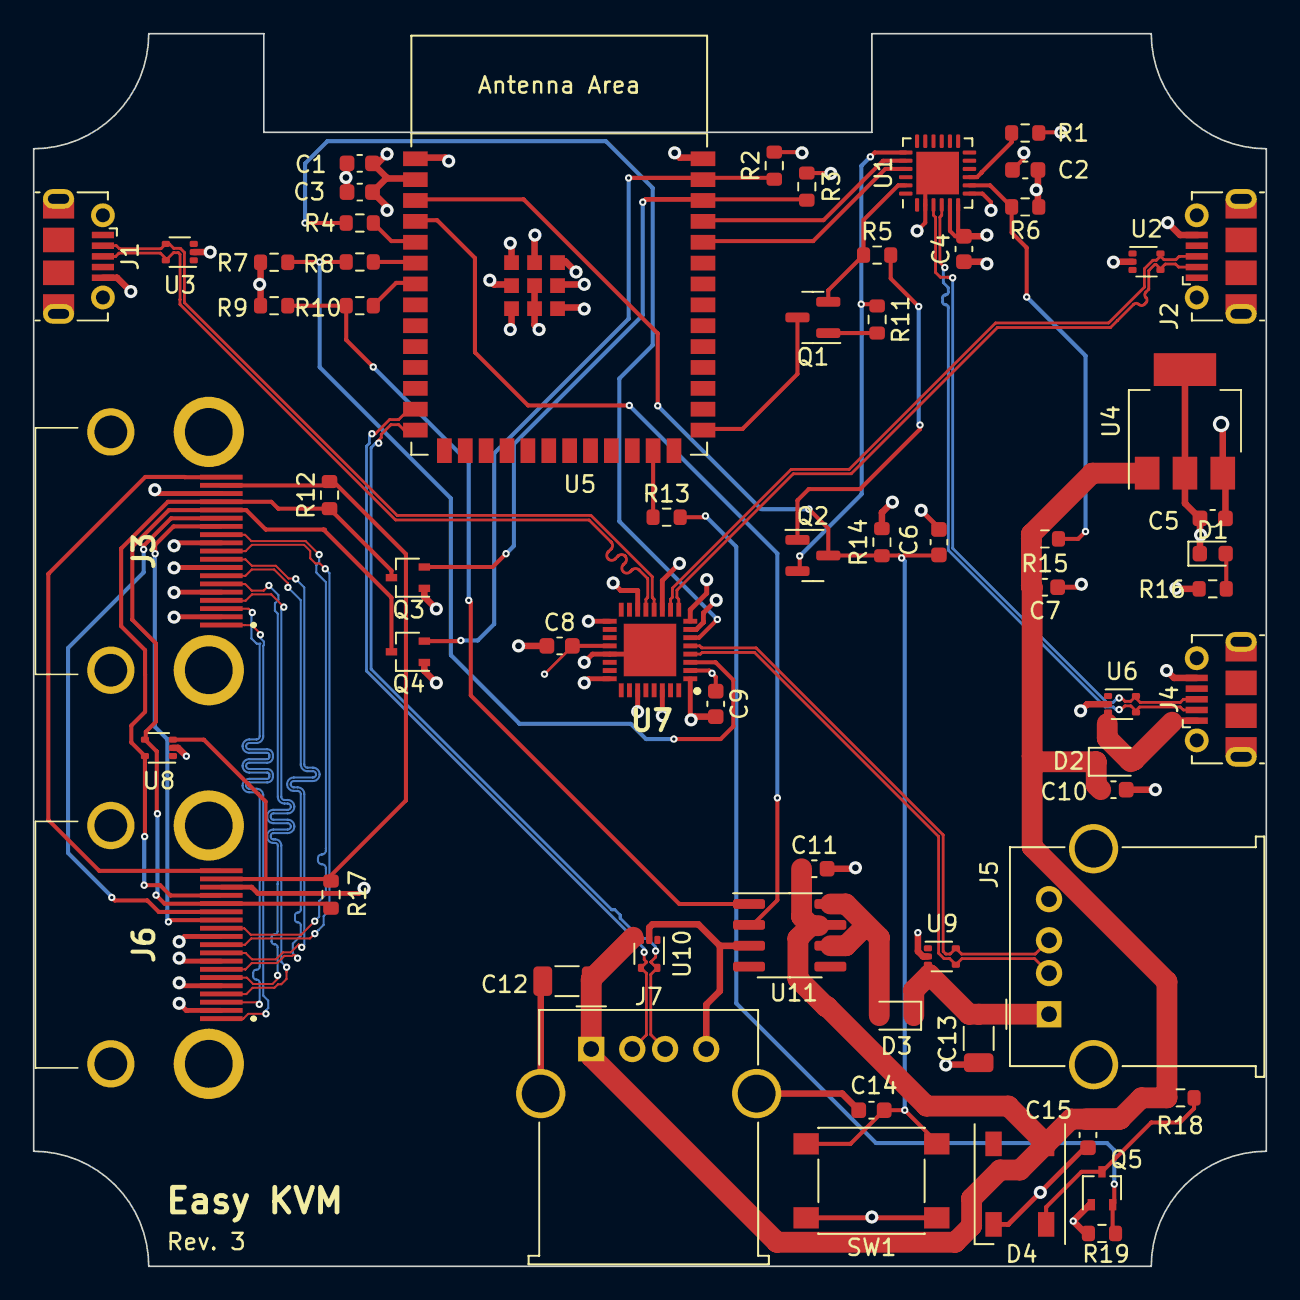
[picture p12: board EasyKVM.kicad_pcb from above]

Board: 4 copper layers, 75.0 x 75.0 mm, 62 parts (0 on the bottom side), 53 nets.

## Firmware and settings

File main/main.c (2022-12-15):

#include "freertos/FreeRTOS.h"
#include "freertos/task.h"
#include "freertos/semphr.h"
#include "esp_log.h"
#include "nvs_flash.h"
#include "esp_spiffs.h"
#include "esp_intr_alloc.h"
#include "usb/usb_host.h"
#include "usb.h"
#include "keyboard.h"
#include "kvm.h"
#include "ddc.h"
#include "ble.h"
#include "wifi.h"
#include "led.h"
#include "webserver.h"
#include "config.h"
#include "health.h"

void app_main(void)
{
    keyboard_handle_t kbd_handle;

    esp_err_t ret = nvs_flash_init();
    if (ret == ESP_ERR_NVS_NO_FREE_PAGES || ret == ESP_ERR_NVS_NEW_VERSION_FOUND)
    {
        ESP_ERROR_CHECK(nvs_flash_erase());
        ESP_ERROR_CHECK(nvs_flash_init());
    }

    esp_vfs_spiffs_conf_t spiffs = 
    {
        .base_path = "/spiffs",
        .partition_label = NULL,
        .max_files = 5,
        .format_if_mount_failed = false
    };
 
    ESP_ERROR_CHECK(esp_vfs_spiffs_register(&spiffs));

    ESP_ERROR_CHECK(usb_preinit());
    ESP_ERROR_CHECK(keyboard_preinit());
    ESP_ERROR_CHECK(kvm_preinit());

    ESP_ERROR_CHECK(led_init());
    ESP_ERROR_CHECK(config_init());
    ESP_ERROR_CHECK(ddc_init());
    ESP_ERROR_CHECK(usb_init());
    ESP_ERROR_CHECK(keyboard_init(&kbd_handle));
    ESP_ERROR_CHECK(wifi_init());
    ESP_ERROR_CHECK(webserver_init());
    ESP_ERROR_CHECK(ble_init());
    ESP_ERROR_CHECK(kvm_init());
}

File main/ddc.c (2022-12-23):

#include <string.h>
#include "freertos/FreeRTOS.h"
#include "freertos/task.h"
#include "freertos/semphr.h"
#include "esp_log.h"
#include "esp_check.h"
#include "usb/usb_host.h"
#include "usb/usb_types_ch9.h"
#include "usb/usb_helpers.h"
#include "driver/i2c.h"
#include "driver/periph_ctrl.h"
#include "rom/ets_sys.h"
#include "ddc_int.h"
#include "ddc.h"

#define TAG "DDC"

esp_err_t ddc_init()
{
    i2c_config_t conf = {};
    conf.mode = I2C_MODE_MASTER;
    conf.sda_io_num = DDC_SDA_GPIO_NUM;
    conf.sda_pullup_en = GPIO_PULLUP_ENABLE;
    conf.scl_io_num = DDC_SCL_GPIO_NUM;
    conf.scl_pullup_en = GPIO_PULLUP_ENABLE;
    //conf.slave.addr_10bit_en = 0;
    //conf.slave.slave_addr = DDC_I2C_ADDRESS;
    conf.master.clk_speed = I2C_MASTER_FREQ_HZ;

    ESP_RETURN_ON_ERROR(i2c_param_config(DDC_I2C_PORT, &conf), TAG, "I2C config failed (%s)", esp_err_to_name(err_rc_));
    ESP_RETURN_ON_ERROR(i2c_driver_install(DDC_I2C_PORT, conf.mode, I2C_MASTER_RX_BUF_DISABLE, I2C_MASTER_TX_BUF_DISABLE, 0), 
        TAG, "I2C driver install failed (%s)", esp_err_to_name(err_rc_));

    return ESP_OK;
}

esp_err_t ddc_reset()
{
    ESP_RETURN_ON_ERROR(i2c_reset_tx_fifo(DDC_I2C_PORT), TAG, "i2c_reset_tx_fifo failed (%s)", esp_err_to_name(err_rc_));
	ESP_RETURN_ON_ERROR(i2c_reset_rx_fifo(DDC_I2C_PORT), TAG, "i2c_reset_tx_fifo i2c_reset_rx_fifo (%s)", esp_err_to_name(err_rc_));
	periph_module_disable(PERIPH_I2C0_MODULE);
    vTaskDelay(100 / portTICK_PERIOD_MS);
	periph_module_enable(PERIPH_I2C0_MODULE);
	ESP_RETURN_ON_ERROR(i2c_driver_delete(DDC_I2C_PORT), TAG, "i2c_driver_delete failed (%s)", esp_err_to_name(err_rc_));

    vTaskDelay(100 / portTICK_PERIOD_MS);
	
    return ddc_init();
}

esp_err_t ddc_set_vcp_internal(uint8_t op, uint16_t value)
{
    esp_err_t ret = ESP_OK;
    uint8_t buffer[8];

    buffer[0] = (DDC_I2C_ADDRESS << 1) | I2C_MASTER_WRITE;
    buffer[1] = 0x51;
    buffer[2] = 0x84;
    buffer[3] = 0x03;
    buffer[4] = op;
    buffer[5] = value >> 8;
    buffer[6] = value & 0xff;
    uint8_t checksum = buffer[0];
    for (int i = 1; i < sizeof(buffer) - 1; i++)
    {
        checksum ^= buffer[i];
    }
    buffer[7] = checksum;

    //int sent = i2c_slave_write_buffer(DDC_I2C_PORT, buffer, sizeof(buffer), 1000 / portTICK_PERIOD_MS);

    i2c_cmd_handle_t cmd = i2c_cmd_link_create();
    ESP_GOTO_ON_ERROR(i2c_master_start(cmd), 
        cleanup, TAG, "set_vcp i2c_master_start failed (%s)", esp_err_to_name(err_rc_));
    ESP_GOTO_ON_ERROR(i2c_master_write_byte(cmd, buffer[0], true), 
        cleanup, TAG, "set_vcp i2c_master_write_byte failed (%s)", esp_err_to_name(err_rc_));
    ESP_GOTO_ON_ERROR(i2c_master_write(cmd, buffer + 1, sizeof(buffer) - 1, true), 
        cleanup, TAG, "set_vcp i2c_master_write failed (%s)", esp_err_to_name(err_rc_));
    ESP_GOTO_ON_ERROR(i2c_master_stop(cmd), 
        cleanup, TAG, "set_vcp i2c_master_stop failed (%s)", esp_err_to_name(err_rc_));
    ESP_GOTO_ON_ERROR(i2c_master_cmd_begin(DDC_I2C_PORT, cmd, DDC_I2C_TIMEOUT), 
        cleanup, TAG, "set_vcp i2c_master_cmd_begin failed (%s)", esp_err_to_name(err_rc_));
    i2c_cmd_link_delete(cmd);
    cmd = NULL;

    vTaskDelay(100 / portTICK_PERIOD_MS);

    ESP_LOGI(TAG, "set vcp 0x%x = 0x%x", op, value);

cleanup:
    if (cmd != NULL)
    {
        i2c_cmd_link_delete(cmd);
        cmd = NULL;
    }

    return ret;
}

esp_err_t ddc_set_vcp(uint8_t op, uint16_t value)
{
    esp_err_t result = ESP_OK;
    for (int i = 1; i <= 10; i++)
    {
        result = ddc_set_vcp_internal(op, value);
        if (result == ESP_OK)
        {
            return ESP_OK;
        }
        ESP_LOGE(TAG, "ddc_set_vcp error %s, retry #%d", esp_err_to_name(result), i);
        vTaskDelay(500 / portTICK_PERIOD_MS);

        ESP_ERROR_CHECK(ddc_reset());
    }
    return result;

}

esp_err_t ddc_get_vcp_internal(uint8_t op, uint16_t* value)
{
    esp_err_t ret = ESP_OK;

    if (value == NULL)
    {
        return ESP_ERR_INVALID_ARG;
    }
    *value = 0;

    uint8_t request_buffer[6];

    request_buffer[0] = (DDC_I2C_ADDRESS << 1) | I2C_MASTER_WRITE;
    request_buffer[1] = 0x51;
    request_buffer[2] = 0x82;
    request_buffer[3] = 0x01;
    request_buffer[4] = op;
    uint8_t checksum = request_buffer[0];
    for (int i = 1; i < sizeof(request_buffer) - 1; i++)
    {
        checksum ^= request_buffer[i];
    }
    request_buffer[5] = checksum;

    i2c_cmd_handle_t cmd = i2c_cmd_link_create();
    ESP_GOTO_ON_ERROR(i2c_master_start(cmd),
        cleanup, TAG, "get_vcp write i2c_master_start failed (%s)", esp_err_to_name(err_rc_));
    ESP_GOTO_ON_ERROR(i2c_master_write_byte(cmd, request_buffer[0], true),
        cleanup, TAG, "get_vcp write i2c_master_write_byte failed (%s)", esp_err_to_name(err_rc_));
    ESP_GOTO_ON_ERROR(i2c_master_write(cmd, request_buffer + 1, sizeof(request_buffer) - 1, true),
        cleanup, TAG, "get_vcp write i2c_master_write failed (%s)", esp_err_to_name(err_rc_));
    ESP_GOTO_ON_ERROR(i2c_master_stop(cmd), cleanup, TAG, "get_vcp write i2c_master_stop failed (%s)", esp_err_to_name(err_rc_));
    ESP_GOTO_ON_ERROR(i2c_master_cmd_begin(DDC_I2C_PORT, cmd, DDC_I2C_TIMEOUT), 
        cleanup, TAG, "get_vcp write i2c_master_cmd_begin failed (%s)", esp_err_to_name(err_rc_));
    i2c_cmd_link_delete(cmd);
    cmd = NULL;

    ets_delay_us(40000);

    uint8_t response_buffer[12];

    memset(response_buffer, 0, sizeof(response_buffer));
    response_buffer[0] = (DDC_I2C_ADDRESS << 1) | I2C_MASTER_READ;

    cmd = i2c_cmd_link_create();
    ESP_GOTO_ON_ERROR(i2c_master_start(cmd), 
        cleanup, TAG, "get_vcp read i2c_master_start failed (%s)", esp_err_to_name(err_rc_));
    ESP_GOTO_ON_ERROR(i2c_master_write_byte(cmd, response_buffer[0], true), 
        cleanup, TAG, "get_vcp read i2c_master_write_byte failed (%s)", esp_err_to_name(err_rc_));
    ESP_GOTO_ON_ERROR(i2c_master_read(cmd, response_buffer + 1, sizeof(response_buffer) - 1, I2C_MASTER_LAST_NACK), 
        cleanup, TAG, "get_vcp read i2c_master_read failed (%s)", esp_err_to_name(err_rc_));
    ESP_GOTO_ON_ERROR(i2c_master_stop(cmd), cleanup, TAG, "get_vcp read i2c_master_stop failed (%s)", esp_err_to_name(err_rc_));
    ESP_GOTO_ON_ERROR(i2c_master_cmd_begin(DDC_I2C_PORT, cmd, DDC_I2C_TIMEOUT), 
        cleanup, TAG, "get_vcp read i2c_master_cmd_begin failed (%s)", esp_err_to_name(err_rc_));
    i2c_cmd_link_delete(cmd);
    cmd = NULL;

    vTaskDelay(100 / portTICK_PERIOD_MS);

    printf("response:");
    for (int i = 0; i < sizeof(response_buffer); i++)
    {
        printf(" %02x", response_buffer[i]);
    }
    printf("\n");

    *value = response_buffer[9] << 8 | response_buffer[10];

cleanup:
    if (cmd != NULL)
    {
        i2c_cmd_link_delete(cmd);
        cmd = NULL;
    }
    return ret;
}
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

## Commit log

2022-10-14 First version (mostly copied from PerfectKVM)
    [partitions.csv]
2022-10-21 over current check
2022-10-21 schematic w/o pull downs and start of pcb
    [ESP32.kicad_sch, EasyKVM.kicad_pcb, EasyKVM.kicad_sch]
2022-10-22 routing start
    [ESP32.kicad_sch, EasyKVM.kicad_pcb, EasyKVM.kicad_sch]
2022-10-25 pcb wip
    [EasyKVM.kicad_pcb]
2022-11-27 design bugs case update software bugs
    [Bottom.3mf, Bottom.step, ESP32.kicad_sch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]
2022-12-11 Fix cornerns Add hub diode R3
    [ESP32.kicad_sch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]
2022-12-15 new case
    [Bottom.3mf, Bottom.step, EasyKVM-case.FCStd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]
2023-07-09 usb resets lower ble advertising reorder references
    [ESP32.kicad_sch, EasyKVM.kicad_pcb, EasyKVM.kicad_sch]
